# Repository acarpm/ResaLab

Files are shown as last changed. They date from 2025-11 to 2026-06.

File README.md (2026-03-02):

# ResaLab





---

**ResaLab** est un projet multidomaine ayant pour objectif de **simplifier et centraliser la procédure de réservation des ressources du FabLab**.  
Il vise à offrir une plateforme fiable, intuitive et interconnectée entre le site web, la base de données et les équipements physiques du FabLab.

---

# 📌 Module matériel – Interface HMI

Le module ResaLab est une **interface homme-machine (IHM)** destinée à être installée directement sur les équipements du FabLab :

- Imprimantes 3D  
- Brodeuses numériques  
- Découpeuses laser  

## 🧩 Composition du module

- 🖥️ Écran **e-ink 2.9"**
- 🔴🟠🟢 Trois LED haute puissance (3W)
- 🔘 Trois boutons lumineux
- 🧠 Module **ESP32-C3**
- ⚡ Alimentation USB-C
- 📐 PCB sur mesure (PCB-A)

---

# 🎯 Fonctionnalités principales

Le module permet :

- ✅ D’afficher l’état de la machine (Disponible / Réservée / En cours)
- 📅 De synchroniser les réservations avec le serveur
- 🔐 De valider localement la présence de l’utilisateur
- 💡 De fournir un retour visuel clair via LED haute puissance
- 🌐 De communiquer en Wi-Fi avec la plateforme centrale

---

# ⚙️ Configuration requise

Certaines constantes doivent être définies dans le firmware :

```cpp
const char* deviceId = "00000001";  // ID du device enregistré sur le serveur

Un fichier identifier.h doit être créé et contenir :

const char* ssid = "";
const char* password = "";
const String serverUrl = "";

``` 

Ce fichier doit être inclus dans le code principal.

---

## Architecture générale du projet

Le projet est divisé en plusieurs domaines complémentaires :

**Site Web**
Plateforme de réservation en ligne
Gestion des utilisateurs et des droits d'accès
Gestion des réservations (création, modification, consultation)
Base de données centralisée
Historique d’utilisation

**Gestion des transactions / crédits**
Carte électronique (ESP32-C3)
Interface Homme-Machine locale
Validation des réservations via API serveur
Autorisation d’accès à l’équipement

Affichage des informations sur écran e-ink
Pilotage des LED 3W
Communication Wi-Fi sécurisée

**Modélisation du boîtier**
Conception 3D du boîtier
Intégration ergonomique des boutons et LEDs
Adaptation aux contraintes d’impression 3D
Optimisation pour maintenance et production FabLab

Voici certaines contraintes à tenir en compte:
Alimentation
Entrée : 5V
Conversion vers 3.3V / 3A
Capacité 3A dimensionnée pour :

Pics Wi-Fi
LED haute puissance
Écran e-ink

## Gestion des LED 3W
Pads TP3 à TP8
Pilotage via transistors Q1, Q2, Q3
Couleurs :
🔴 Rouge
🟠 Orange
🟢 Vert

*GPIO LED*
green  = 0
orange = 9
red    = 1

*Boutons lumineux*
Pads TP9 à TP17

## Interface écran e-ink (SPI 4 lignes)

Écran 2.9 connecté via SPI. https://github.com/WeActStudio/WeActStudio.EpaperModule

Mapping GPIO
MOSI : 7
SCLK : 6
CS   : 10
DC   : 8
RST  : 3
BUSY : 2

Connexion prévue via dupont wires.

GPIO supplémentaires

Les GPIO restants sont exposés via le connecteur J3.
Permet d’ajouter des périphériques ou de réaliser des tests.

## État du projet

Version actuelle : PCB-A (Proof of Concept)

## État du projet

La première version de la PCB a servi de **Proof of Concept (PoC)**.

Une nouvelle révision est prévue afin de :

- Corriger les défauts de la V1
- Permettre la programmation directement via le port **USB-C d’alimentation**
- Simplifier l’intégration et améliorer la fiabilité

---

## Roadmap (prévisionnelle)

- [ ] Révision PCB V2
- [ ] Intégration module ESP32-C3
- [ ] Support complet OTA
- [ ] Intégration avec le système de réservation (backend ResaLab)

---

## Statut

Projet en développement actif.  
Version actuelle : Prototype fonctionnel (PoC).

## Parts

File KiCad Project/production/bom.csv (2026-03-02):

Designator | Footprint | Quantity | Value | LCSC Part #
B7, B8, B9, W1, W2, W3, W4, W5, W6 | SolderWirePad_1x01_SMD_1x2mm | 9 | ~
C1A1, C1B1 | 0805 | 2 | 10uF
C1C1, C3 | 0805 | 2 | 0.1uF
C2A1, C2B1 | 1206 | 2 | 22uF
C4 | 0805 | 1 | 22nF
C5 | 0805 | 1 | 470pF
D1 | 0805 | 1 | LED
F1 | FUSC4632X85N | 1 | MF-MSMF050-2
IC1 | SOTFL50P160X60-8N | 1 | MP2338GTL-P
J1, J3 | PinHeader_1x08_P2.54mm_Vertical | 2 | Conn_01x08_Pin
J2 | USB_C_Receptacle_GCT_USB4105-xx-A_16P_TopMnt_Horizontal | 1 | USB_C_Receptacle_USB2.0_16P
L1 | MPLAL60606R8 | 1 | 6.8uH
Q1, Q2, Q3 | SOT-23 | 3 | AO3400A
R1 | 0805 | 1 | 51k
R10, R12, R15 | 0805 | 3 | 100
R11, R13, R14, R6 | 0805 | 4 | 10k
R2 | 0805 | 1 | 9.09k
R3 | 0805 | 1 | 191k
R4 | 0805 | 1 | 49.9k
R5 | 0805 | 1 | 100k
R7, R8 | 0603 | 2 | 5.1k
R9 | 2816 | 1 | 0.68
TP1 | TestPoint_Pad_D1.5mm | 1 | OUT 3V3
TP2 | TestPoint_Pad_D1.5mm | 1 | gnd
U1 | XCVR_ESP32-C3-DEVKITM-1 | 1 | ESP32-C3-DEVKITM-1
WG1 | SolderWirePad_1x01_SMD_1x2mm | 1 | 3V3 LEDG
WG2 | SolderWirePad_1x01_SMD_1x2mm | 1 | GND LEDG
WO1 | SolderWirePad_1x01_SMD_1x2mm | 1 | 3V3 LEDO
WO2 | SolderWirePad_1x01_SMD_1x2mm | 1 | GND LED3
WR1 | SolderWirePad_1x01_SMD_1x2mm | 1 | 3V3 LEDR
WR2 | SolderWirePad_1x01_SMD_1x2mm | 1 | GND LEDR

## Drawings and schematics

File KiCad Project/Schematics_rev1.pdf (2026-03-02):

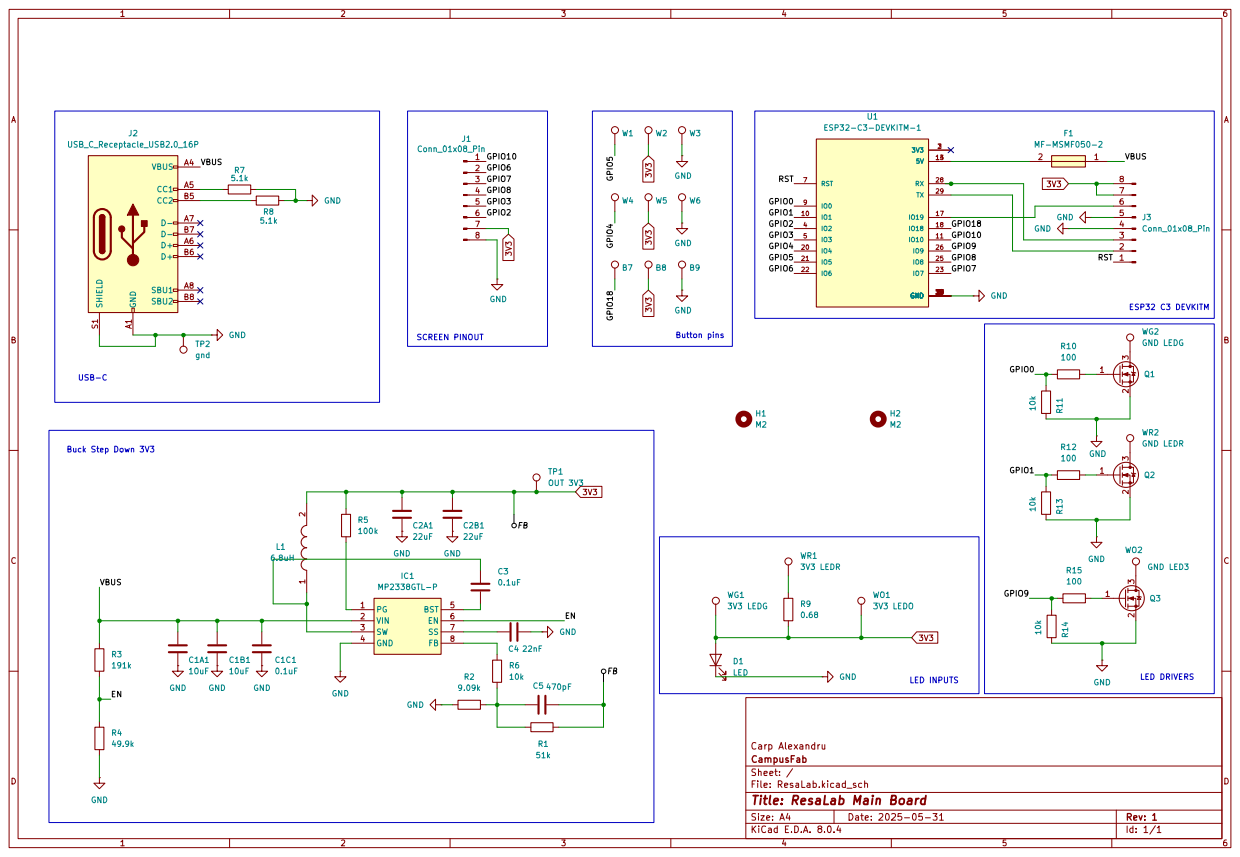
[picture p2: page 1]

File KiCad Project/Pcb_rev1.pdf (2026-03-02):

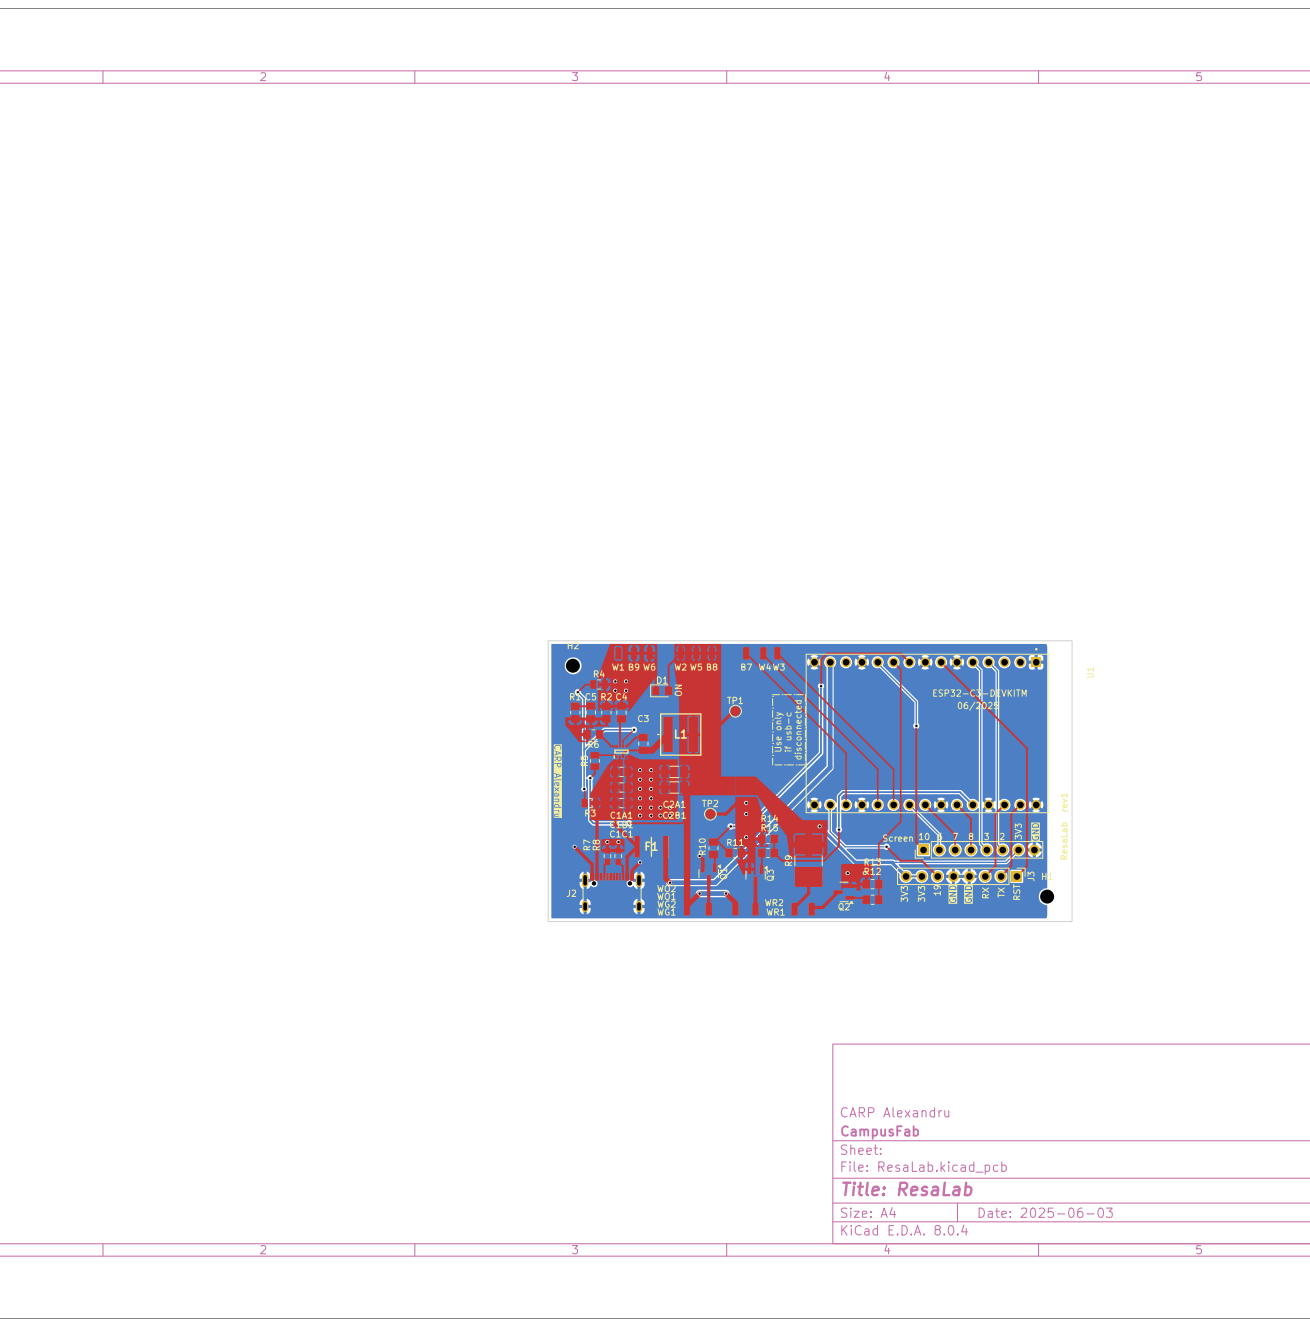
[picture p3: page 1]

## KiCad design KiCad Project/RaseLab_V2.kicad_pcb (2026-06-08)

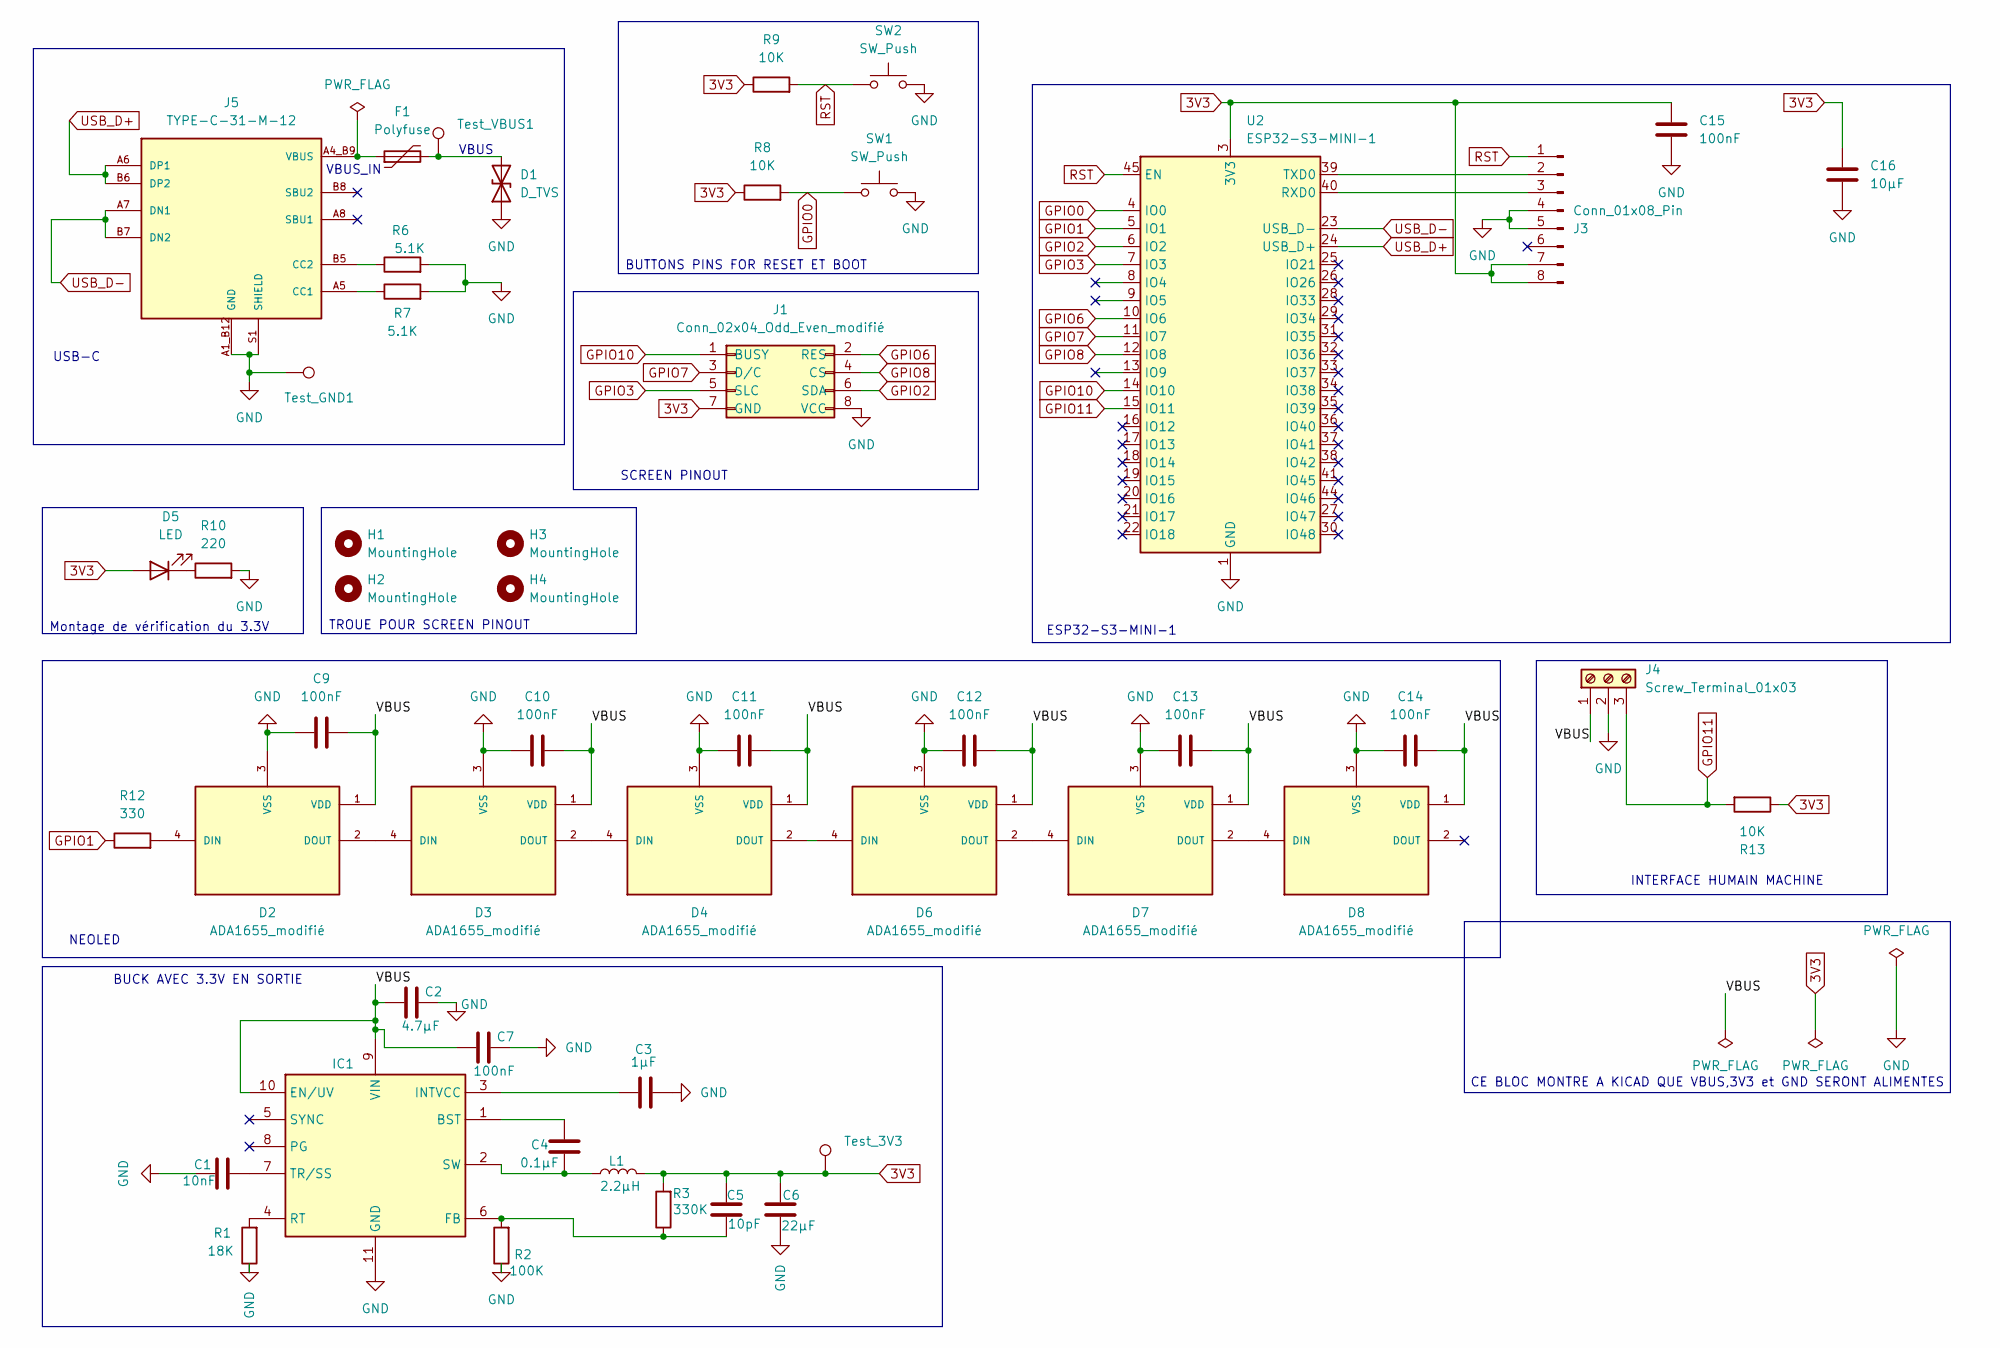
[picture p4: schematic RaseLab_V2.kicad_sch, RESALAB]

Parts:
C1: 10nF; C_0603_1608Metric
C2: 4.7µF; C_0603_1608Metric
C3: 1µF; C_0603_1608Metric
C4: 0.1µF; C_0603_1608Metric
C5: 10pF; C_0603_1608Metric
C6: 22µF; C_0603_1608Metric
C7, C9, C10, C11, C12, C13, C14, C15: 100nF; C_0603_1608Metric
C16: 10µF; C_0603_1608Metric
D1: D_TVS; D_SOD-123
D2, D3, D4, D6, D7, D8: ADA1655_modifié; LED_WS2812B_PLCC4_5.0x5.0mm_P3.2mm; PARTREV N/A
D5: LED; LED_0603_1608Metric
F1: Polyfuse; Fuse_1206_3216Metric
H1, H2, H3, H4: MountingHole; MountingHole_2.2mm_M2
IC1: LT8607EMSE#TRPBF; SOP50P490X110-11N; Mouser Part Number 584-LT8607EMSE#TRPBF
J1: Conn_02x04_Odd_Even_modifié; PinHeader_2x04_P2.54mm_Vertical
J3: Conn_01x08_Pin; PinHeader_1x08_P2.54mm_Horizontal
J4: Screw_Terminal_01x03; TerminalBlock_MaiXu_MX126-5.0-03P_1x03_P5.00mm
J5: TYPE-C-31-M-12; HRO_TYPE-C-31-M-12; PARTREV 2020.12.08
L1: 2.2µH; L_2010_5025Metric
R1: 18K; R_0603_1608Metric
R2: 100K; R_0603_1608Metric
R3: 330K; R_0603_1608Metric
R6, R7: 5.1K; R_0603_1608Metric
R8, R9, R13: 10K; R_0603_1608Metric
R10: 220; R_0603_1608Metric
R12: 330; R_0603_1608Metric
SW1, SW2: SW_Push; SW_SPST_PTS645Sx43SMTR92
Test_3V3: TestPoint; TestPoint_Pad_1.0x1.0mm
Test_GND1: TestPoint; TestPoint_Pad_1.0x1.0mm
Test_VBUS1: TestPoint; TestPoint_Pad_1.0x1.0mm
U2: ESP32-S3-MINI-1; XCVR_ESP32-S3-MINI-1-N8

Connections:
3V3: C5.2, C6.2, C15.1, C16.1, D5.2 (A), J1.7 (GND), J3.7, J3.8, L1.2, R3.2, R8.1, R9.1, R13.1, Test_3V3.1 (1_1), U2.3 (3V3)
GND: C1.2, C2.1, C3.1, C6.1, C7.1, C9.1, C10.1, C11.1, C12.1, C13.1, C14.1, C15.2, C16.2, D1.1 (A1), D2.3 (VSS), D3.3 (VSS), D4.3 (VSS), D6.3 (VSS), D7.3 (VSS), D8.3 (VSS), IC1.11 (GND), J1.8 (VCC), J3.4, J3.5, J4.2, J5.A1_B12 (GND), J5.S1 (SHIELD), R1.1, R2.1, R6.2, R7.2, R10.2, SW1.2, SW2.2, Test_GND1.1 (1_1), U2.1 (GND), U2.2 (GND), U2.42 (GND), U2.43 (GND), U2.46 (GND), U2.47 (GND), U2.48 (GND), U2.49 (GND), U2.50 (GND), U2.51 (GND), U2.52 (GND), U2.53 (GND), U2.54 (GND), U2.55 (GND), U2.56 (GND), U2.57 (GND), U2.58 (GND), U2.59 (GND), U2.60 (GND), U2.61 (GND), U2.62 (GND), U2.63 (GND), U2.64 (GND), U2.65 (GND)
GPIO0: R8.2, SW1.1, U2.4 (IO0)
GPIO1: R12.1, U2.5 (IO1)
GPIO2: J1.6 (SDA), U2.6 (IO2)
GPIO3: J1.5 (SLC), U2.7 (IO3)
GPIO6: J1.2 (RES), U2.10 (IO6)
GPIO7: J1.3 (D/C), U2.11 (IO7)
GPIO8: J1.4 (CS), U2.12 (IO8)
GPIO10: J1.1 (BUSY), U2.14 (IO10)
GPIO11: J4.3, R13.2, U2.15 (IO11)
unnamed: D1.2 (A2), F1.2, Test_VBUS1.1 (1_1)
unnamed: D2.4 (DIN), R12.2
unnamed: D2.2 (DOUT), D3.4 (DIN)
unnamed: D3.2 (DOUT), D4.4 (DIN)
unnamed: D4.2 (DOUT), D6.4 (DIN)
unnamed: D5.1 (K), R10.1
unnamed: D6.2 (DOUT), D7.4 (DIN)
unnamed: D7.2 (DOUT), D8.4 (DIN)
unnamed: C4.2, IC1.1 (BST)
unnamed: C5.1, IC1.6 (FB), R2.2, R3.1
unnamed: C3.2, IC1.3 (INTVCC)
unnamed: IC1.4 (RT), R1.2
unnamed: C4.1, IC1.2 (SW), L1.1
unnamed: C1.1, IC1.7 (TR/SS)
unnamed: J3.2, U2.39 (TXD0)
unnamed: J3.3, U2.40 (RXD0)
unnamed: J5.A5 (CC1), R7.1
unnamed: J5.B5 (CC2), R6.1
RST: J3.1, R9.2, SW2.1, U2.45 (EN)
USB_D+: J5.A6 (DP1), J5.B6 (DP2), U2.24 (USB_D+)
USB_D-: J5.A7 (DN1), J5.B7 (DN2), U2.23 (USB_D-)

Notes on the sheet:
USB-C
BUCK AVEC 3.3V EN SORTIE
VBUS_IN
TROUE POUR SCREEN PINOUT
SCREEN PINOUT
VBUS
INTERFACE HUMAIN MACHINE
CE BLOC MONTRE A KICAD QUE VBUS,3V3 et GND SERONT ALIMENTES
NEOLED
ESP32-S3-MINI-1
Montage de vérification du 3.3V
BUTTONS PINS FOR RESET ET BOOT

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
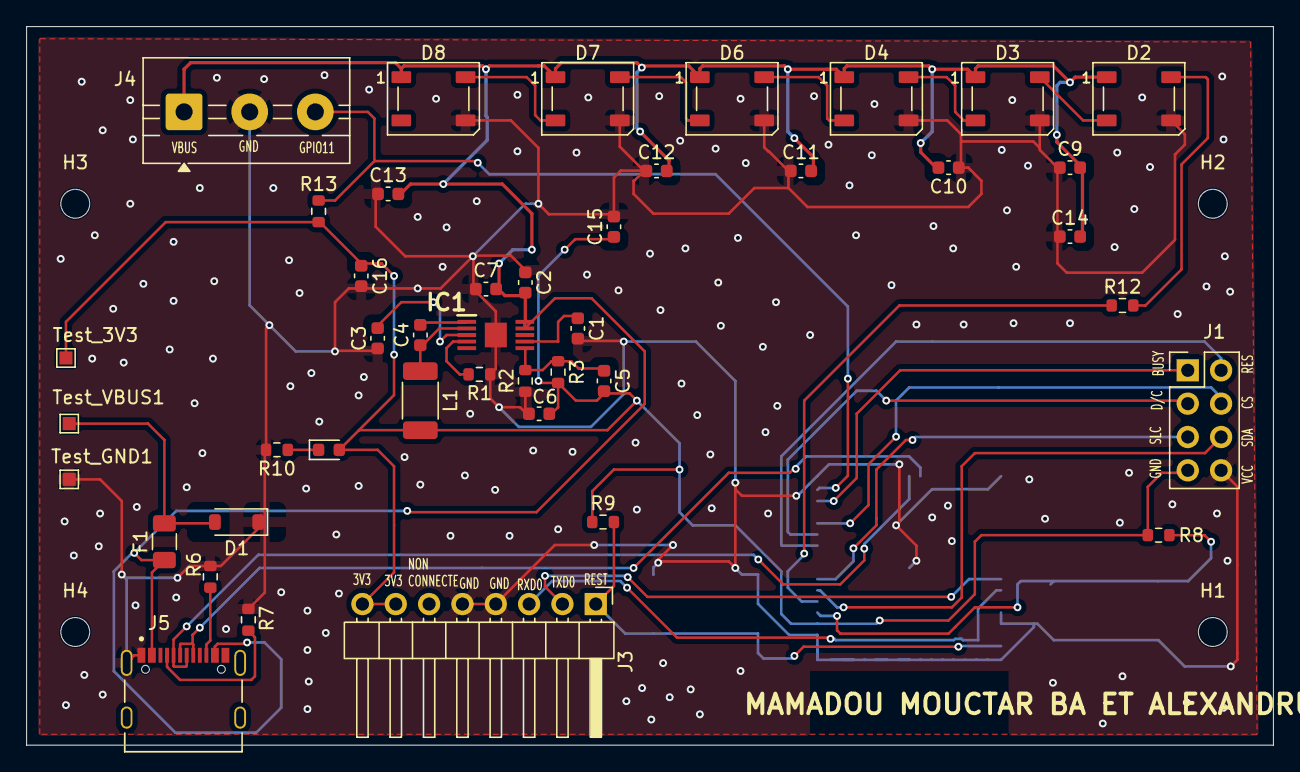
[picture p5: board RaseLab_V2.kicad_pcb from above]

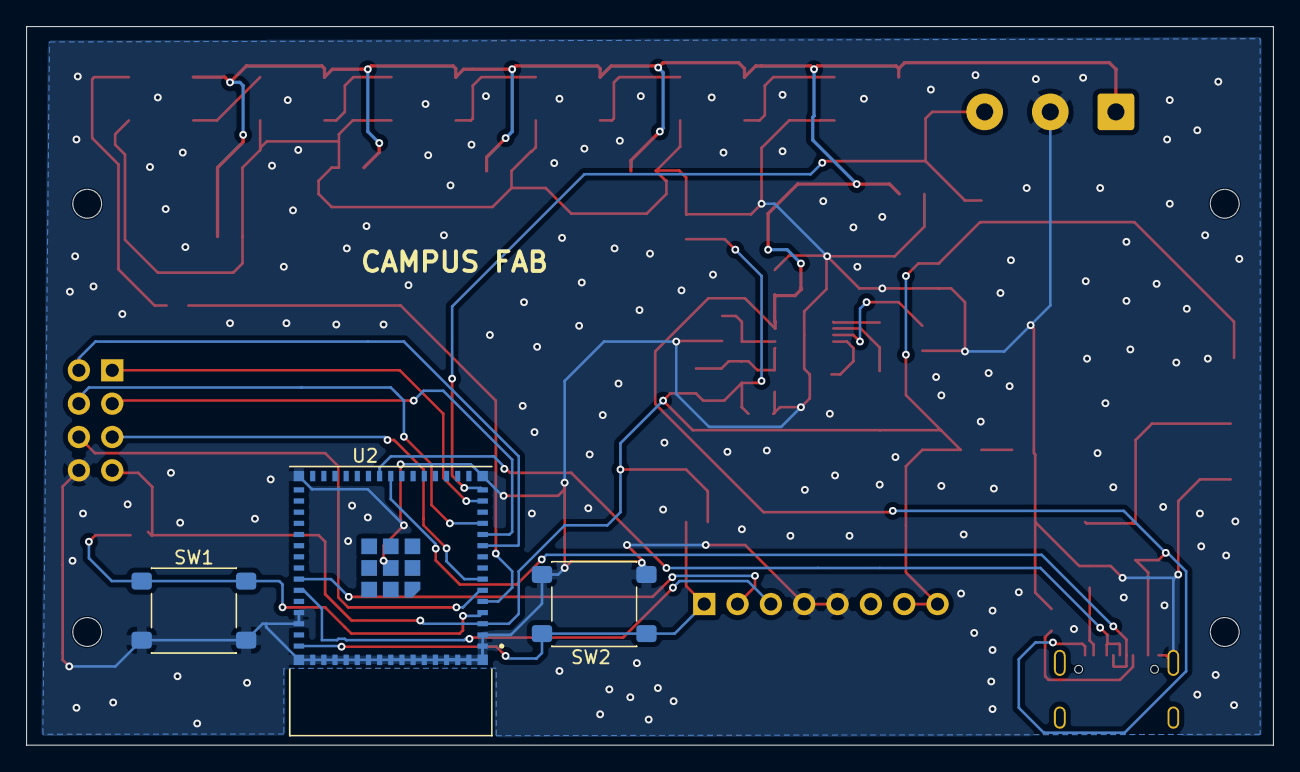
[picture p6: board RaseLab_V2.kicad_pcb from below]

Board: 2 copper layers, 95.0 x 54.8 mm, 50 parts (3 on the bottom side), 33 nets.

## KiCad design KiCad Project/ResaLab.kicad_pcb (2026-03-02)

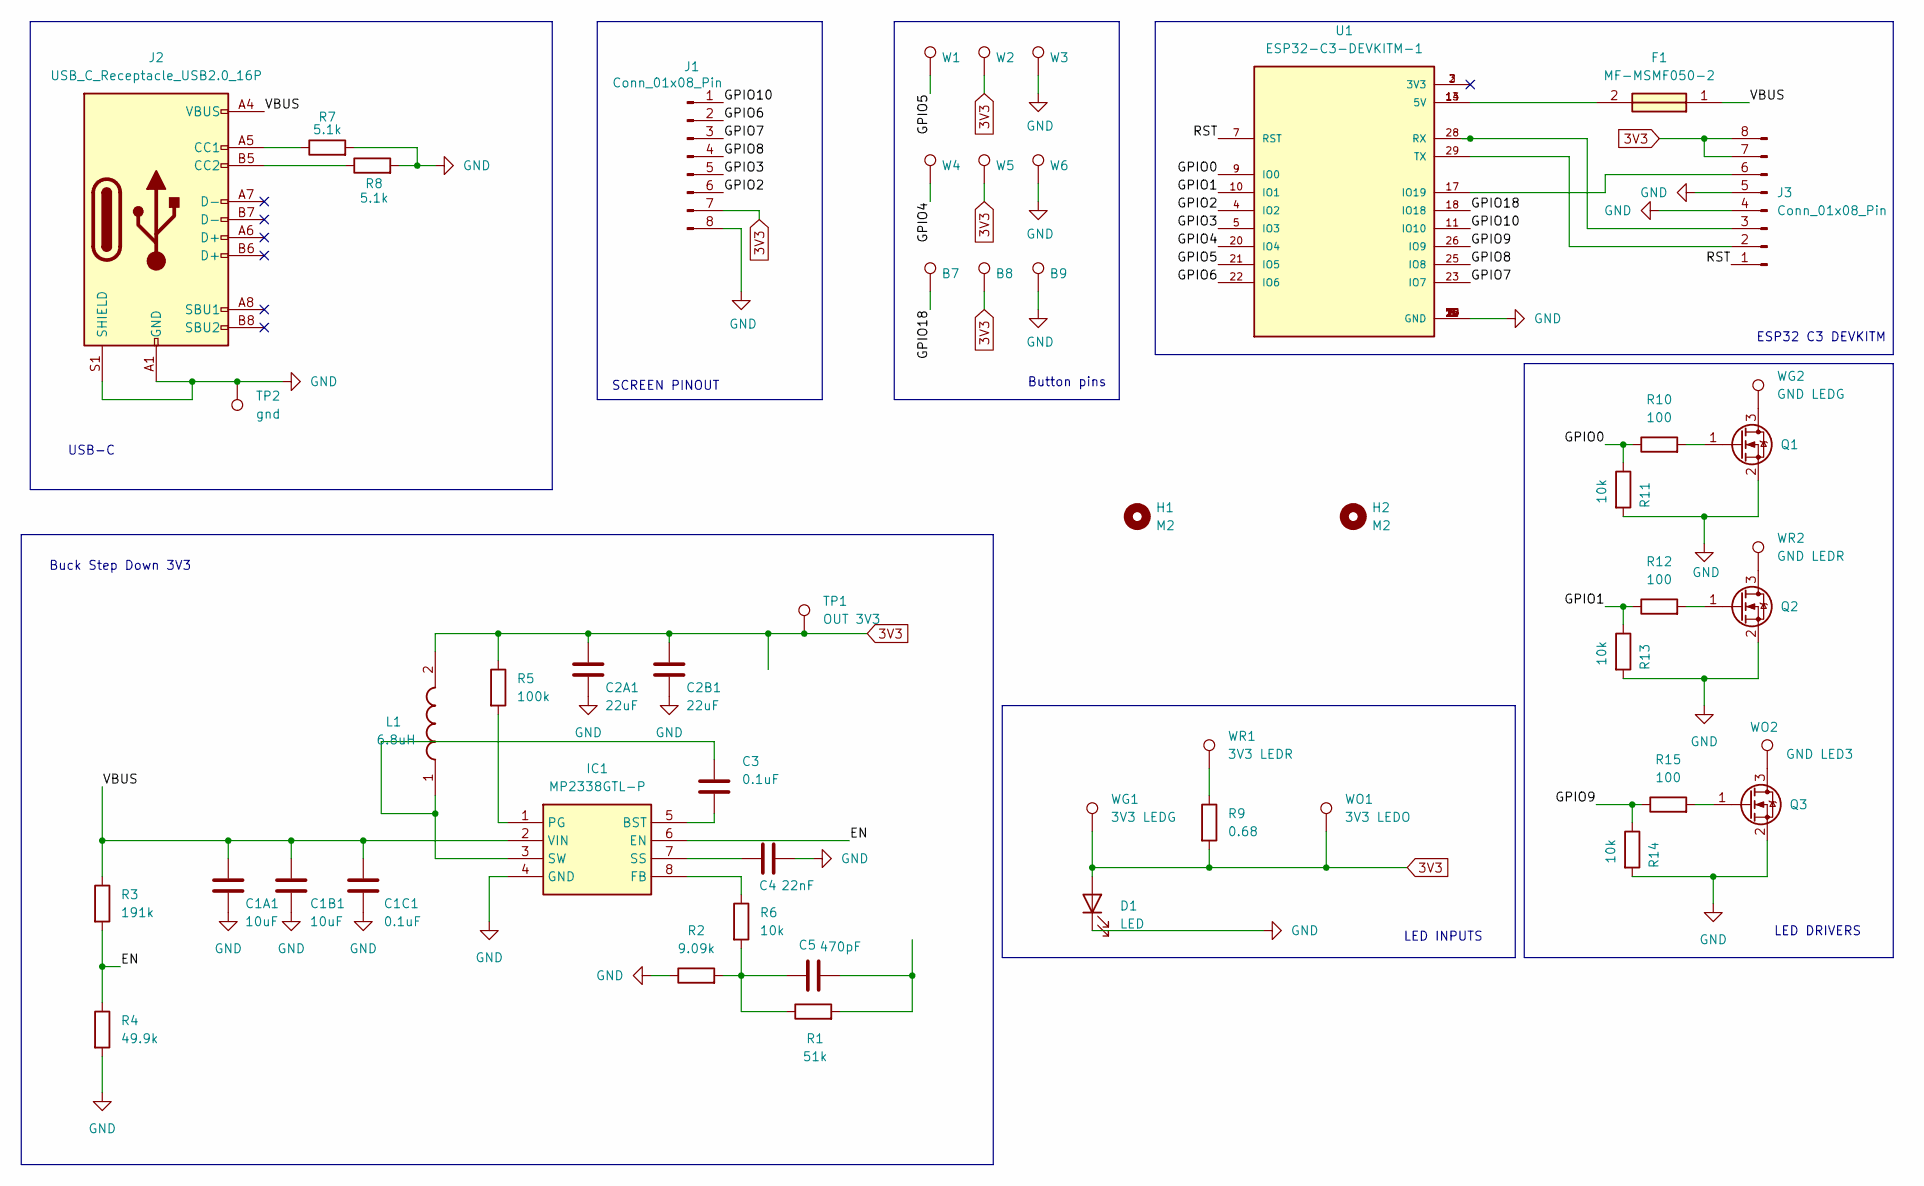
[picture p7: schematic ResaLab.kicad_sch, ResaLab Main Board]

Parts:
B7, B8, B9: SolderWirePad_1x01_SMD_1x2mm
C1A1, C1B1: 10uF; C_0805_2012Metric_Pad1.18x1.45mm_HandSolder
C1C1, C3: 0.1uF; C_0805_2012Metric_Pad1.18x1.45mm_HandSolder
C2A1, C2B1: 22uF; C_1206_3216Metric_Pad1.33x1.80mm_HandSolder
C4: 22nF; C_0805_2012Metric_Pad1.18x1.45mm_HandSolder
C5: 470pF; C_0805_2012Metric_Pad1.18x1.45mm_HandSolder
D1: LED; LED_0805_2012Metric_Pad1.15x1.40mm_HandSolder
F1: MF-MSMF050-2; FUSC4632X85N; Mouser Part Number 652-MF-MSMF050-2
H1, H2: M2; MountingHole_2.2mm_M2
IC1: MP2338GTL-P; SOTFL50P160X60-8N; Mouser Part Number 946-MP2338GTL-P
J1, J3: Conn_01x08_Pin; PinHeader_1x08_P2.54mm_Vertical
J2: USB_C_Receptacle_USB2.0_16P; USB_C_Receptacle_GCT_USB4105-xx-A_16P_TopMnt_Horizontal
L1: 6.8uH; MPLAL60606R8; Mouser Part Number 946-MPL-AL6060-6R8
Q1, Q2, Q3: AO3400A; SOT-23
R1: 51k; R_0805_2012Metric_Pad1.20x1.40mm_HandSolder
R2: 9.09k; R_0805_2012Metric_Pad1.20x1.40mm_HandSolder
R3: 191k; R_0805_2012Metric
R4: 49.9k; R_0805_2012Metric
R5: 100k; R_0805_2012Metric
R6, R11, R13, R14: 10k; R_0805_2012Metric_Pad1.20x1.40mm_HandSolder
R7, R8: 5.1k; R_0603_1608Metric_Pad0.98x0.95mm_HandSolder
R9: 0.68; R_2816_7142Metric_Pad3.20x4.45mm_HandSolder
R10, R12, R15: 100; R_0805_2012Metric_Pad1.20x1.40mm_HandSolder
TP1: OUT 3V3; TestPoint_Pad_D1.5mm
TP2: gnd; TestPoint_Pad_D1.5mm
U1: ESP32-C3-DEVKITM-1; XCVR_ESP32-C3-DEVKITM-1
W1, W2, W3, W4, W5, W6: SolderWirePad_1x01_SMD_1x2mm
WG1: 3V3 LEDG; SolderWirePad_1x01_SMD_1x2mm
WG2: GND LEDG; SolderWirePad_1x01_SMD_1x2mm
WO1: 3V3 LEDO; SolderWirePad_1x01_SMD_1x2mm
WO2: GND LED3; SolderWirePad_1x01_SMD_1x2mm
WR1: 3V3 LEDR; SolderWirePad_1x01_SMD_1x2mm
WR2: GND LEDR; SolderWirePad_1x01_SMD_1x2mm

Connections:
3V3: B8.1, C2A1.1, C2B1.1, D1.2 (A), J1.7, J3.7, J3.8, L1.2, R5.1, R9.2, TP1.1, W2.1, W5.1, WG1.1, WO1.1
/EN: IC1.6 (EN), R3.2, R4.1
/GPIO0: R10.1, R11.1, U1.9 (IO0)
/GPIO1: R12.1, R13.1, U1.10 (IO1)
/GPIO2: J1.6, U1.4 (IO2)
/GPIO3: J1.5, U1.5 (IO3)
/GPIO4: U1.20 (IO4), W4.1
/GPIO5: U1.21 (IO5), W1.1
/GPIO6: J1.2, U1.22 (IO6)
/GPIO7: J1.3, U1.23 (IO7)
/GPIO8: J1.4, U1.25 (IO8)
/GPIO9: R14.1, R15.1, U1.26 (IO9)
/GPIO10: J1.1, U1.11 (IO10)
/GPIO18: B7.1, U1.18 (IO18)
/RST: J3.1, U1.7 (RST)
/VBUS: C1A1.1, C1B1.1, C1C1.1, F1.1, IC1.2 (VIN), J2.A4 (VBUS), J2.A9 (VBUS), J2.B4 (VBUS), J2.B9 (VBUS), R3.1
GND: B9.1, C1A1.2, C1B1.2, C1C1.2, C2A1.2, C2B1.2, C4.2, D1.1 (K), IC1.4 (GND), J1.8, J2.A1 (GND), J2.A12 (GND), J2.B1 (GND), J2.B12 (GND), J2.S1 (SHIELD), J3.4, J3.5, Q1.2 (S), Q2.2 (S), Q3.2 (S), R2.1, R4.2, R7.2, R8.2, R11.2, R13.2, R14.2, TP2.1, U1.1 (GND), U1.6 (GND), U1.8 (GND), U1.12 (GND), U1.15 (GND), U1.16 (GND), U1.19 (GND), U1.24 (GND), U1.27 (GND), U1.30 (GND), W3.1, W6.1
unnamed: C5.1, R1.1, R2.2, R6.2
unnamed: C5.2, R1.2
unnamed: F1.2, U1.13 (5V), U1.14 (5V)
unnamed: C3.2, IC1.5 (BST)
unnamed: IC1.8 (FB), R6.1
unnamed: IC1.1 (PG), R5.2
unnamed: C4.1, IC1.7 (SS)
unnamed: C3.1, IC1.3 (SW), L1.1
unnamed: J2.A5 (CC1), R7.1
unnamed: J2.B5 (CC2), R8.1
unnamed: J3.2, U1.29 (TX)
unnamed: J3.3, U1.28 (RX)
unnamed: J3.6, U1.17 (IO19)
unnamed: Q1.3 (D), WG2.1
unnamed: Q1.1 (G), R10.2
unnamed: Q2.3 (D), WR2.1
unnamed: Q2.1 (G), R12.2
unnamed: Q3.3 (D), WO2.1
unnamed: Q3.1 (G), R15.2
unnamed: R9.1, WR1.1

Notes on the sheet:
ESP32 C3 DEVKITM
USB-C
LED DRIVERS
LED INPUTS
Buck Step Down 3V3
SCREEN PINOUT
Button pins

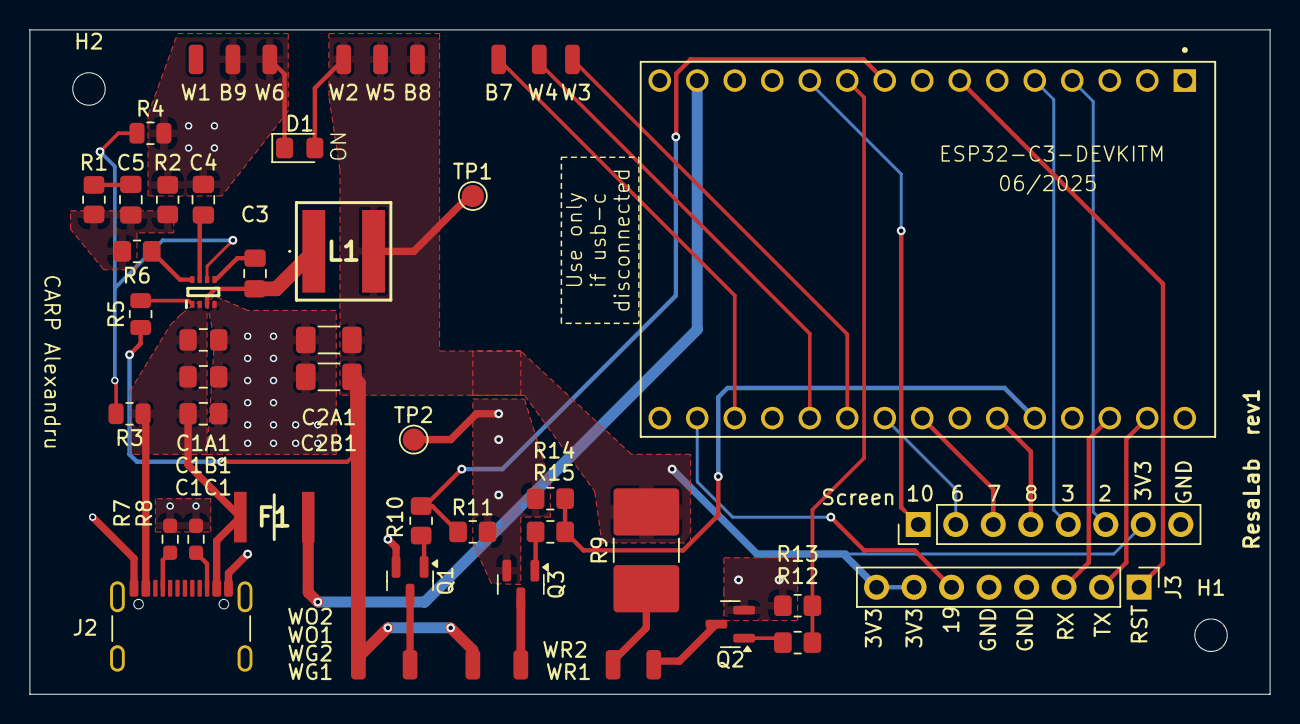
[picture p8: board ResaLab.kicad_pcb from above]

Board: 2 copper layers, 84.0 x 45.0 mm, 53 parts (0 on the bottom side), 37 nets.

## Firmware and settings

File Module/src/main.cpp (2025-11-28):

#include <Arduino.h>
#include <WiFi.h>

#include <time.h>

#include <ScreenOutput.h>
#include <ServerConnection.h>

#include <led.h>
#include <button.h>

#include "Identifier.h"

/*
==================================================================================================
                                        CONFIGURATION
==================================================================================================
*/

#define GREEN_LED_PIN 9
#define ORANGE_LED_PIN 0
#define RED_LED_PIN 1

#define LEFT_BUTTON_PIN 18
#define MIDDLE_BUTTON_PIN 5

#define RESERVATION_TIME 15 // in minutes

#define DELAY_BETWEEN_CHECKS_CONNECTION 30000 // in milliseconds
#define DELAY_BETWEEN_CHECKS_NO_RESERVATION 15000 // in milliseconds
#define DELAY_BETWEEN_CHECKS_HOURS 15000 // in milliseconds

#define TIME_BEFORE_SHOWING_RESERVATION 180

#define RESERVATION_CANCELLED "4" // Reservation state for cancelled in the sql enum
#define RESERVATION_ONGOING "1" // Reservation state for ongoing in the sql enum

const char* deviceId = "00000016";  // Id of the device registered on the server

const long gmtOffset_sec = 3600;   // GMT offset in seconds

/*
==================================================================================================
                                        SCRIPT
==================================================================================================
*/

extern "C" int lwip_hook_ip6_input(void *p) {
  return 1; // Retourne 1 pour indiquer que le paquet IPv6 est accepté
}

ServerConnection server;

ScreenOutput screenOutput;

Led greenLed = Led(GREEN_LED_PIN);
Led orangeLed = Led(ORANGE_LED_PIN);
Led redLed = Led(RED_LED_PIN);

Button leftButton = Button(LEFT_BUTTON_PIN);
Button middleButton = Button(MIDDLE_BUTTON_PIN);

const char* ntpServer = "pool.ntp.org";    // NTP server 
const int daylightOffset_sec = 3600;      // Daylight saving time offset in seconds

bool checkWifiConnection();

void mainScreen();

int checkReservations();

void changeReservationState(String reservationID, String newState);

void getReservationName(String reservationID, String& name, String& surname);

void getTime(int* hours, int* minutes);

String formatTime(int time);

bool isConnected = false;

void setup() {
  int currentHour, currentMinute;

  Serial.println("Starting ResaLab...");

  screenOutput.begin();
  WiFi.begin(ssid, password);
  server.connect(serverUrl);
  server.checkConnection();


  while (!isConnected) {
    isConnected = checkWifiConnection();
  }

  configTime(gmtOffset_sec, daylightOffset_sec, ntpServer);

  screenOutput.resetScreen();

  getTime(&currentHour, &currentMinute);

  screenOutput.showHour(currentHour, currentMinute);
  screenOutput.showInternetState(true, WiFi.RSSI());
}

uint64_t lastTimeConnectionCheck = 0, lastTimeReservationCheck = 0, lastTimeScreenUpdated = 0;

bool isToValid = true;
int currentReservationId = -1;

void loop() {

  if (millis() - lastTimeConnectionCheck > DELAY_BETWEEN_CHECKS_CONNECTION || !isConnected) {
    lastTimeConnectionCheck = millis();
    isConnected = checkWifiConnection();
  }

  if (!isConnected) {
    screenOutput.showInternetState(false);
    return;
  }

  if (millis() - lastTimeScreenUpdated > DELAY_BETWEEN_CHECKS_HOURS) {
    lastTimeScreenUpdated = millis();

    int currentHour, currentMinute;
    getTime(&currentHour, &currentMinute);

    screenOutput.showHour(currentHour, currentMinute);
    screenOutput.showInternetState(true, WiFi.RSSI());
  }

  if (millis() - lastTimeReservationCheck > DELAY_BETWEEN_CHECKS_NO_RESERVATION) {
    lastTimeReservationCheck = millis();
    log_v("Checking reservations...");
    currentReservationId = checkReservations();
  }

  if (currentReservationId == -2) {
    screenOutput.showText("Erreur de connexion au serveur");
    return;
  }

  if (leftButton.isPressed() && isToValid && currentReservationId != -1) {
    changeReservationState((String)currentReservationId, RESERVATION_ONGOING);
    isToValid = false;
  }

  if (middleButton.isPressed() && currentReservationId != -1) {
    changeReservationState((String)currentReservationId, RESERVATION_CANCELLED);
    isToValid = false;
    redLed.off();
    greenLed.on();
    orangeLed.off();
  }
}

int checkReservations() {
  int httpResponseCode = 0;

  int errorCode = server.sendRequest(GET_NEXT_RESERVATION, strlen(GET_NEXT_RESERVATION), deviceId, strlen(deviceId), &httpResponseCode);
  String response = server.getResponse();

  if (errorCode != CODE_SUCCESS) {
    log_e("Failed to send get next reservation request. Error code: %d", errorCode);
    return -1;
  }

  log_d("Server response: %s", response.c_str());

  String serverResponseCode = response.substring(0, 3);

  if (serverResponseCode.equals(INVALID_RESERVATION)) {
    log_i("No reservation found.");
    greenLed.on();
    redLed.off();
    orangeLed.off();
    screenOutput.showText("Aucune reservation");
    return -1;
  }

  int reservationId = response.substring(3, 8).toInt();
  bool reservationComing = response.substring(8, 9).toInt();
  int startReservationTimestamp = response.substring(9, 19).toInt();
  int endReservationTimestamp = response.substring(19, 29).toInt();

  log_v("Server response code: %s", serverResponseCode.c_str());
  log_v("reservationComing: %d", reservationComing);
  log_v("reservationId: %d", reservationId);
  log_v("startReservationTimestamp: %d", startReservationTimestamp);
  log_v("endReservationTimestamp: %d", endReservationTimestamp);

  time_t now = time(nullptr);
  if (now == -1) {
    log_e("Failed to obtain timestamp");
    return -1;
  }

  log_v("Current timestamp: %ld", now);

  if (!reservationComing && now > startReservationTimestamp && now < endReservationTimestamp) {
    redLed.on();
    greenLed.off();
    orangeLed.off();

    String name = "";
    String surname = "";
    getReservationName((String)currentReservationId, name, surname);
    getReservationName(String(reservationId), name, surname);
    screenOutput.showText("Reservation en cours : ", name + " " + surname);

    int progression = (int)(((float)(now - startReservationTimestamp) / (float)(endReservationTimestamp - startReservationTimestamp)) * 100);
    screenOutput.showProgressionBar(progression);
    
  } else if ( now > startReservationTimestamp && now < startReservationTimestamp + RESERVATION_TIME * 60) {
    greenLed.off();
    redLed.off();
    orangeLed.on();
    isToValid = true;
    screenOutput.showText("Validez la reservation");
  } else {
    redLed.off();
    greenLed.on();
    orangeLed.off();
    if ( now + TIME_BEFORE_SHOWING_RESERVATION * 60 > startReservationTimestamp) {
      // Adding 60 seconds to round up.
      int timeBeforeReservation = startReservationTimestamp - now + 60;

      screenOutput.showText("Prochaine reservation dans", formatTime(timeBeforeReservation));
    } else {
      screenOutput.showText("Machine Libre");
    }
  }
  

  if (reservationComing && now > startReservationTimestamp + RESERVATION_TIME * 60) {
    changeReservationState(String(reservationId), RESERVATION_CANCELLED);
    isToValid = false;
    redLed.off();
    greenLed.on();
    orangeLed.off();
  }

  return reservationId;
}

void changeReservationState(String reservationID, String newState) {
  int httpResponseCode = 0;

  log_d("ID : %s, new state : %s", reservationID.c_str(), newState.c_str());

  String payload = "";
  for (int i = reservationID.length(); i < 5; i++) {
    payload += "0";
  }
  payload += reservationID;
  for (int i = newState.length(); i < 3; i++) {
    payload += "0";
  }
  payload += newState;

  int errorCode = server.sendRequest(CHANGE_RESERVATION_STATE, strlen(CHANGE_RESERVATION_STATE), payload.c_str(), payload.length(), &httpResponseCode);
  String response = server.getResponse();

  if (errorCode != CODE_SUCCESS) {
    log_e("Failed to send change reservation state request. Error code: %d", errorCode);
    return;
  }
  log_d("Server response: %s", response.c_str());

  String serverResponseCode = response.substring(0, 3);

  if (serverResponseCode.equals(RESERVATION_STATE_CHANGED)) {
    log_i("Reservation state changed successfully.");
    return;
  } else {
    log_e("Failed to change reservation state.");
    return;
  }
}

bool checkWifiConnection() {
  uint8_t errorCode;

  errorCode = server.checkConnection();

  if (errorCode == CODE_SUCCESS) {
    return true;
  }

  log_d("Connection lost. Error code: %d", errorCode);

  WiFi.reconnect();
  errorCode = server.reconnect();

  if (errorCode == ERROR_WIFI_DISCONNECTED) {
    log_v("Wifi disconnected");
    orangeLed.blink(1000);
    return false;
  }

  if (errorCode == ERROR_SERVER_DISCONNECTED) {
    log_v("Server disconnected");
    orangeLed.blink(250, 1000);
    return false;
  }

  return true;
}

void getReservationName(String reservationID, String& name, String& surname) {
  int httpResponseCode = 0;

  // Pad reservation ID with leading zeros to ensure it is 8 characters long
  String payload = "";
  for (int i = reservationID.length(); i < 8; i++) {
    payload += "0";
  }
  payload += reservationID;

  int errorCode = server.sendRequest(GET_RESERVATION_NAME, strlen(GET_RESERVATION_NAME), payload.c_str(), payload.length(), &httpResponseCode);
  String response = server.getResponse();

  if (errorCode != CODE_SUCCESS) {
    log_e("Failed to get reservation name. Error code: %d", errorCode);
    name = String(errorCode);
    surname = "";
    return;
  }

  log_d("Server response: %s", response.c_str());

  String serverResponseCode = response.substring(0, 3);

  if (serverResponseCode.equals(INVALID_RESERVATION)) {
    log_e("Invalid reservation ID.");
    name = serverResponseCode;
    surname = "";
    return;
  }

  if (serverResponseCode.equals(USER_NOT_FOUND)) {
    log_e("User not found for reservation ID: %s", reservationID.c_str());
    name = serverResponseCode;
    surname = "";
    return;
  }

  // Remove the first 3 characters which represent the response code
  response = response.substring(3); // Remove response code

  // Split the response into name and surname using '&' as the delimiter
  // Example response: "Mouchere&Ludovic"
  int sep = response.indexOf('&');
  if (sep < 0) {
    name = response;
    surname = "";
    return;
  }

  name = response.substring(0, sep);
  surname = response.substring(sep + 1);
}

/**
 * @brief Retrieves the current local time and stores the hours and minutes.
 * 
 * @param[out] hours Pointer to an integer where the current hour (0-23) will be stored.
 * @param[out] minutes Pointer to an integer where the current minute (0-59) will be stored.
 * 
 */
void getTime(int* hours, int* minutes) {
  time_t now = time(nullptr);
  struct tm* timeinfo = localtime(&now);
  *hours = timeinfo->tm_hour;
  *minutes = timeinfo->tm_min;
}

/**
 * @brief Formats a time value in seconds into a human-readable string format.
 * 
 * @param time The time value in seconds to be formatted.
 * @return String A formatted time string in the format "Xh Ym" (if hours > 0) 
 *         or "Ym" (if hours == 0), where X is hours and Y is minutes.
 * 
 * @note If the input time is less than 60 seconds, it will be displayed as "0m".
 * 
 */
String formatTime(int time) {
  int minutes, hours;

  minutes = time / 60;
  hours = minutes / 60;
  minutes = minutes % 60;

  String timeFormatted = "";

  if (hours > 0) {
    timeFormatted += String(hours) + "h";
  }
  timeFormatted += String(minutes) + "m" ;

  return timeFormatted;
}

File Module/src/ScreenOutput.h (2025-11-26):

#ifndef SCREENOUTPUT_H
#define SCREENOUTPUT_H

#include <GxEPD2_BW.h>
#include <Fonts/FreeSansBold10pt7b.h>

#include "logo.h"

#include <SPI.h>

#define SS_PIN 10   // Chip Select pin for SPI
#define DC_PIN 8    // Data/Command pin for SPI
#define RES_PIN 3   // Reset pin for SPI
#define BUSY_PIN 2  // Busy pin for SPI

#define SCK_PIN 6   // Serial Clock pin for SPI
#define MISO_PIN 19 // Master In Slave Out pin for SPI. We are not supposed to use it, but must define it.
#define MOSI_PIN 7  // Master Out Slave In pin for SPI

// WiFi RSSI thresholds (in dBm)
#define GOOD_WIFI_RSSI -50
#define MEDIUM_WIFI_RSSI -60

// WiFi logo dimensions and position
#define WIFI_LOGO_X 280
#define WIFI_LOGO_Y 0
#define WIFI_LOGO_WIDTH 16
#define WIFI_LOGO_HEIGHT 16

// CampusFab logo dimensions and position
#define CAMPUSFAB_LOGO_WIDTH 128
#define CAMPUSFAB_LOGO_HEIGHT 127
#define CAMPUSFAB_LOGO_X 84
#define CAMPUSFAB_LOGO_Y 0

// Hour display box
#define HOUR_X 0
#define HOUR_Y 0
#define HOUR_WIDTH 58
#define HOUR_HEIGHT 22

// Maximum characters per line for text display
#define MAX_CHARACTER 27

// Text box dimensions and position
#define TEXT_BOX_X 0
#define TEXT_BOX_Y 22
#define TEXT_BOX_WIDTH 296
#define TEXT_BOX_HEIGHT 106
#define TEXT_LINE_HEIGHT 19
#define TEXT_START_X (TEXT_BOX_X + 2)
#define TEXT_START_Y (TEXT_BOX_Y + 44)

// Progress bar dimensions and position
#define PROGRESS_BAR_X 2
#define PROGRESS_BAR_Y 106
#define PROGRESS_BAR_WIDTH 292 // MUST BE > 4
#define PROGRESS_BAR_HEIGHT 20 // MUST BE > 4


class ScreenOutput {

    private:

        int lastWifiState = -1;
        // Wifi logos for different signal strengths available in logo.h.
        const uint8_t* wifiLogo[4] = {Wifi_Logo_0, Wifi_Logo_1, Wifi_Logo_2, Wifi_Logo_3};


        GxEPD2_BW<GxEPD2_290_BS, GxEPD2_290_BS::HEIGHT> display;

        /**
         * @brief Initialize and render the e-paper display with the CampusFab logo.
         *
         * This function performs the necessary initialization and first-frame rendering
         * for the e-paper display used by the application.
         * Clears the display to white and sets default text drawing properties (text color and font).
         * Performs an initial full display update.
         * Draws the CampusFab logo.
         * 
         * @note This function relies on several external objects.
         *      FreeSansBold10pt7b  : font used for text rendering.
         *      CampusFab_Logo      : bitmap data for the logo.
         * 
         */
        void initDisplay() {
            display.fillScreen(GxEPD_WHITE);

            // Other font available in Adafruit_GFX library 
            display.setFont(&FreeSansBold10pt7b);
            display.setTextColor(GxEPD_BLACK);
            
            display.display();

            // Display CampusFab logo Filling black first then showing logo
            display.fillScreenPartial(GxEPD_BLACK, 0, 0, GxEPD2_290_BS::HEIGHT, GxEPD2_290_BS::WIDTH);
            display.fillScreenPartial(GxEPD_WHITE, CAMPUSFAB_LOGO_X, CAMPUSFAB_LOGO_Y, CAMPUSFAB_LOGO_WIDTH, CAMPUSFAB_LOGO_HEIGHT);
            // CampusFab logo in logo.h
            display.drawInvertedBitmap(CAMPUSFAB_LOGO_X, CAMPUSFAB_LOGO_Y, CampusFab_Logo, CAMPUSFAB_LOGO_WIDTH, CAMPUSFAB_LOGO_HEIGHT, GxEPD_BLACK);
            display.refresh(true);
            display.display(true);
        } 

    public:
        ScreenOutput()
            : display(GxEPD2_290_BS(SS_PIN, DC_PIN, RES_PIN, BUSY_PIN))
        {}

        /**
         * @brief Initialize the SPI bus and the display.
         *
         * Intended usage: Call once during system startup (for example in setup()) before performing 
         * any drawing or display updates.
         * 
         */
        void begin() {
            log_d("Initializing display...");
            SPI.begin(SCK_PIN, MISO_PIN, MOSI_PIN, SS_PIN);
            display.init(115200, true, 50, false);
            display.setRotation(1);
            display.setFullWindow();
            initDisplay();
        }

        /**
         * @brief Clear the e-paper display and refresh the physical screen.
         * 
         */
        void resetScreen() {
            display.fillScreen(GxEPD_WHITE);
            display.display();
        }

        /**
         * @brief Displays the current hour and minute on the e-paper display.
         * 
         * This function renders a time display in HH:MM format with leading zeros.
         * 
         * @param hour The hour value to display
         * @param minute The minute value to display
         * 
         */
        void showHour(int hour, int minute) {
            // BOX
            display.fillScreenPartial(GxEPD_BLACK, HOUR_X, HOUR_Y, HOUR_WIDTH, HOUR_HEIGHT);
            display.fillScreenPartial(GxEPD_WHITE, HOUR_X, HOUR_Y, HOUR_WIDTH - 2, HOUR_HEIGHT - 2);

            if (hour < 0 || hour > 23 || minute < 0 || minute > 59) {
                log_e("Invalid time: %02d:%02d", hour, minute);
                display.display(true);
                return;
            }

            display.setCursor(HOUR_X + 2, HOUR_Y + 15);
            display.print(hour < 10 ? "0" : "");
            display.print(hour);
            display.print(":");
            display.print(minute < 10 ? "0" : "");
            display.print(minute);
            display.display(true);
        }

        /**
         * @brief Displays the current internet connection state on the screen with a WiFi icon.
         * 
         * @param connected Boolean indicating whether the device is connected to the internet.
         * @param rssi The Received Signal Strength Indicator value in dBm.
         * 
         */
        void showInternetState(bool connected, int rssi = 0) {
            int internetState = 0;

            if (connected) {
                if (rssi >= GOOD_WIFI_RSSI) {
                    internetState = 3;
                } else if (rssi >= MEDIUM_WIFI_RSSI) {
                    internetState = 2;
                } else {
                    internetState = 1;
                }
            }
            
            // No change in state, no need to update display, saving time and power.
            if (internetState == lastWifiState) {
                return;
            }

            lastWifiState = internetState;

            // BOX
            display.fillScreenPartial(GxEPD_BLACK, WIFI_LOGO_X - 2, WIFI_LOGO_Y - 2, WIFI_LOGO_WIDTH + 4, WIFI_LOGO_HEIGHT + 6);
            display.fillScreenPartial(GxEPD_WHITE, WIFI_LOGO_X, WIFI_LOGO_Y, WIFI_LOGO_WIDTH, WIFI_LOGO_HEIGHT + 2);

            display.drawInvertedBitmap(WIFI_LOGO_X, WIFI_LOGO_Y, wifiLogo[internetState], WIFI_LOGO_WIDTH, WIFI_LOGO_HEIGHT, GxEPD_BLACK);
            
            display.refresh(WIFI_LOGO_X, WIFI_LOGO_Y, WIFI_LOGO_WIDTH, WIFI_LOGO_HEIGHT);
            display.display(true);
        }
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

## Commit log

2025-09-09 New button and change State Reservation Request
2025-10-31 Change RESERVATION_CANCELLED value from '2' to '4'
    Pfff compliqué la vie
2025-11-24 Update README with status badges and GPIO info removal
    Removed GPIO pin assignments and added status badges.
2025-11-27 Update deviceId in README to new value
2026-03-02 Better Project Organisation
    [ResaLab.kicad_pcb, ResaLab.kicad_sch, bom.csv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]
2026-06-05 Revert "Add files via upload"
    This reverts commit a9c3518be7772360b13313472f6971113314537d.
    [RESALAB_V2.step, RaseLab_V2.kicad_pcb, RaseLab_V2.kicad_sch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]
2026-06-05 feat(kicad): add name to component card
    [RaseLab_V2.kicad_pcb, RaseLab_V2.kicad_sch]
2026-06-08 RECTIFATION DE CERTAINS ERREURS
    [RaseLab_V2.kicad_pcb, RaseLab_V2.kicad_sch]
2026-06-08 AJOUT DES NONS SUR LES CONNECTEURS EXTERNES
    [RaseLab_V2.kicad_pcb]
